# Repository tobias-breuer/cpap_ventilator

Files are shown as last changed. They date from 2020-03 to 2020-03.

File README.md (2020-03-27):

# CPAP Ventilator

CPAP (Continous positive airway pressure)-ventilation is a common form of medical therapy when people suffer from sleep related respiratory problems like sleep apnoa. Worn at night, these masks keep the patients' respiratory tracts open by inducing a continous overpressure. CPAP units are available in large numbers in common households as well as in hospitals.

More information is available [on this page](https://www.uni-marburg.de/de/fb13/halbleiterphotonik/the-breathing-project/the-breathing-project-1/the-cpap-solution).

## Hardware components

### Arduino UNO Schematic Wiring

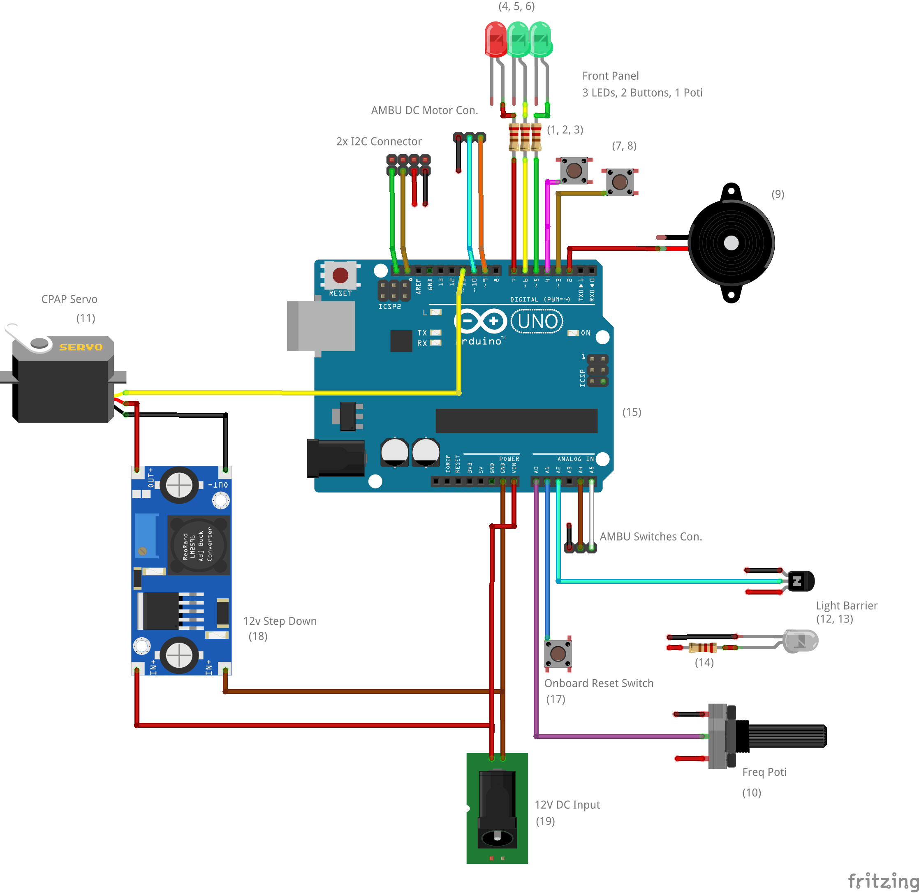
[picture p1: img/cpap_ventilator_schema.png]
Arduino UNO Wiring


### Arduino UNO Pinout

```
  -DPIN_SPEAKER=2
  -DPIN_SWITCH_MODE_A=3
  -DPIN_SWITCH_MODE_B=4
  -DPIN_SWITCH_RESET=A1
  -DPIN_LED_MODE_ONE=5
  -DPIN_LED_MODE_TWO=6
  -DPIN_LED_WARN=7
  -DPIN_SERVO=11
  -DPIN_LIGHT=12
  -DPIN_POTI=A0
  -DPIN_MOTOR_STOP=8
  -DPIN_MOTOR_IN3=9
  -DPIN_MOTOR_IN4=10
```

## Deploying the Code

The project is now maintained as as a [platformio project](https://platformio.org), in order to manage dependencies and compatibility with other platforms.

The project can be build and flashed using:

```
pio run -t upload -e uno_cpap  # for the CPAP board
pio run -t upload -e uno_ambu  # for the Ambu Bag board
```

## Discussion

### Servo latency

The tube is not completely closed until the servo is done. In other words, the
air pressure is practically the same until completed. So we have to subtract the
running time from the time interval until the next closing.

We have measured for 1:1 and 1:2 resulting in an offset of round about 0.18
seconds off. This _magic_ value is removed as `SERVO_CLOSE_LATENCY`.

### EEPROM state

Some state variables, e.g., the cycle counter or the last mode, are stored in
the Arduino's EEPROM. Thus these values can be stored reboot-safe.

However, at the initial boot those values might be not nulled. So the controller
should be reset via the reset button at the first start.

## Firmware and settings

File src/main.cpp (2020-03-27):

#include <Arduino.h>
#include <Wire.h>
#include <LiquidCrystal_I2C.h>

#include "./button.h"
#include "./error.h"
#include "./state.h"

#ifdef MODE_AMBU
#include "./ambu.h"
#elif MODE_CPAP
#include "./cpap.h"
#else
#error neither MODE_AMBU nor MODE_CPAP were specified
#endif

/* Signatures of all following functions */
inline void display_error();
inline void display_status();
inline void read_frequency();
inline void read_mode();
inline void reset();
void loop();
void setup();

/* Reference to the LCD */
LiquidCrystal_I2C lcd(0x27);

/* Variable to measure the breaths per minute */
volatile float breaths_per_minute;

/**
 * Setup the CPAP device. This function is run once while booting up.
 */
void setup() {
  Serial.begin(9600);
  Serial.println("[info] ventilator booting up...");

  // init pins of LEDs as outputs
  pinMode(PIN_LED_MODE_ONE, OUTPUT);
  pinMode(PIN_LED_MODE_TWO, OUTPUT);
  pinMode(PIN_LED_WARN, OUTPUT);
  pinMode(PIN_SPEAKER, OUTPUT);

  // set output signals to low
  digitalWrite(PIN_LED_MODE_ONE, LOW);
  digitalWrite(PIN_LED_MODE_TWO, LOW);
  digitalWrite(PIN_LED_WARN, LOW);
  digitalWrite(PIN_SPEAKER, LOW);

  // init input pins as input with internal pullups
  pinMode(PIN_SWITCH_MODE_A, INPUT_PULLUP);
  pinMode(PIN_SWITCH_MODE_B, INPUT_PULLUP);
  pinMode(PIN_SWITCH_RESET, INPUT_PULLUP);

  // init display
  Wire.begin();
  lcd.begin(16, 2);

  // mode specific setup
#ifdef MODE_AMBU
  ambu_setup();
#elif MODE_CPAP
  cpap_setup();
#endif
}

/**
 * Reset the device's state to a factory mode.
 *
 * This implies a reset of all LEDs and the states stored in the EEPROM.
 * This function should be called after assembly and after the replacement of
 * some hardware.
 */
inline void reset() {
  Serial.println("[warn] entering reset function, cleaning all data...");

#ifdef MODE_AMBU
  ambu_reset();
#elif MODE_CPAP
  cpap_reset();
#endif

  cycle_count_reset();
  mode_reset();

  error = err_none;

  digitalWrite(PIN_LED_MODE_ONE, LOW);
  digitalWrite(PIN_LED_MODE_TWO, LOW);
  digitalWrite(PIN_LED_WARN, LOW);
  digitalWrite(PIN_SPEAKER, LOW);
}

/**
 * Read the mode from the slide switch and notify potential updates.
 */
inline void read_mode() {
  int tmp_mode = mode_read();

  debounce_btn(PIN_SWITCH_MODE_A, 500) { tmp_mode = 0; }
  debounce_btn(PIN_SWITCH_MODE_B, 500) { tmp_mode = 1; }

  if (tmp_mode != mode_read()) {
    mode_write(tmp_mode);
  }
}

/**
 * Read the potentiometer's value and convert it to breaths per minute.
 */
inline void read_frequency() {
  // map the values of the poti to the breaths per minute
  // map() cannot be used, since it only works for int values

  const float poti = analogRead(PIN_POTI);
  breaths_per_minute = (poti - POTI_MIN) * (BPM_MAX - BPM_MIN) / (POTI_MAX - POTI_MIN) + BPM_MIN;
}

/**
 * Display the state on an external LCD display.
 */
inline void display_status() {
  lcd.home();
  lcd.print("Breaths/Min: ");
  lcd.print(breaths_per_minute);
  lcd.setCursor(0, 1);
  lcd.print("In-/Exhale: ");
  lcd.print(mode_get().mult_inhale);
  lcd.print(" ");
  lcd.print(mode_get().mult_exhale);
}

/**
 * Display the error with different blinkings on the warning LED.
 */
inline void display_error() {
  static volatile unsigned long next_blink_switch = 0;

  switch (error) {
    case err_light_barrier:
      // A defect light barrier is critical and results in a permanent light
      digitalWrite(PIN_LED_WARN, HIGH);
      break;

    case err_cycle_count:
      // Exceeding the threshold results in a flashing
      if (next_blink_switch == 0 || (millis() >= next_blink_switch)) {
        next_blink_switch = millis() + WARN_BLINK_MS;
        digitalWrite(PIN_LED_WARN, !digitalRead(PIN_LED_WARN));
      }
      break;

    case err_none:
    default:
      digitalWrite(PIN_LED_WARN, LOW);
  }
}

/**
 * Main loop, which is called endlessly during execution.
 */
void loop() {
  read_mode();

  // show state on the two state LEDs
  digitalWrite(PIN_LED_MODE_ONE, mode_read() == 0);
  digitalWrite(PIN_LED_MODE_TWO, mode_read() == 1);

  read_frequency();

  display_status();

  // warn if cycle_count is greater than MAX_CYCLE_COUNT
  cycle_warn_display();

  // A more urgent specific error might overwrite the previous cycle warning.
#ifdef MODE_AMBU
  ambu_loop();
#elif MODE_CPAP
  cpap_loop();
#endif

  display_error();

  // reset the device if the reset button is pressed
  debounce_btn(PIN_SWITCH_RESET, 1000) {
    reset();
  }
}

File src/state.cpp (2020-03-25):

#include <Arduino.h>
#include <EEPROM.h>

#include "./error.h"
#include "./state.h"

const int eeprom_cycle_count = 0x00;
const int eeprom_mode = eeprom_cycle_count + sizeof(long unsigned int);

/**
 * Variable used for local caching to not query the EEPROM too much.
 * One MUST NOT use this variable. Just use the functions!
 */
long unsigned int cycle_cache = 0;
int mode_cache = -1;

void cycle_count_reset() {
  cycle_cache = 0;
  EEPROM.put(eeprom_cycle_count, cycle_cache);

  Serial.println("[info] writing cycle counter to EEPROM: 0");
}

long unsigned int cycle_count_read() {
  if (cycle_cache == 0) {
    EEPROM.get(eeprom_cycle_count, cycle_cache);
  }

  return cycle_cache;
}

long unsigned int cycle_count_increment() {
  cycle_cache = cycle_count_read() + 1;

  // only store every CYCLE_MOD_SYNC-nth iteration a value
  if ((cycle_cache > 0) && (cycle_cache % CYCLE_MOD_SYNC == 0)) {
    EEPROM.put(eeprom_cycle_count, cycle_cache);

    Serial.print("[info] writing cycle counter to EEPROM: ");
    Serial.println(cycle_cache);
  }

  return cycle_cache - 1;
}

void cycle_warn_display() {
  static bool cycle_warn_raised = false;

  if (cycle_warn_raised) {
    return;
  }

  if (cycle_count_read() >= MAX_CYCLE_COUNT) {
    Serial.println("[warn] reached cycle count threshold");
    error = err_cycle_count;

    cycle_warn_raised = true;
  }
}

void mode_reset() {
  mode_write(0);
}

int mode_read() {
  if (mode_cache == -1) {
    EEPROM.get(eeprom_mode, mode_cache);
  }

  return mode_cache;
}

mode_t mode_get() {
  // update mode_cache, if necessary
  mode_read();

  // return a default iff the value is invalid
  if (mode_cache < 0 || mode_cache >= mode_sizeof) {
    return modes[0];
  }

  return modes[mode_cache];
}

void mode_write(int index) {
  mode_cache = index;
  EEPROM.put(eeprom_mode, mode_cache);

  Serial.print("[info] writing mode to EEPROM: ");
  Serial.println(mode_cache);
}

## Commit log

2020-03-19 Servo_ver2 is just a basic script with rotation around 95 degree and back of the servo ... TwoModeVersion_withAmplitudeControlPot has two modes with blinking LED for OneOne and OneTwo ratio and poten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
2020-03-19 Add files via upload
    added loopcount and LED warning after definable number of loop iterations
2020-03-19 Added LoopReset with blinking LED
2020-03-19 add version with bump sensor (debouncing not correct, yet) ... newest version of amplitudecontrolpot with two modes
2020-03-20 delte basic servo code
2020-03-20 working version for CPAP with 2 modes, LEDs and Speaker warning for loopcount
2020-03-21 Extract pin variables to defines
2020-03-21 Replace interrupt based button with a slide switch
    Also enable basic Serial based logging.
    [main.cpp]
2020-03-21 added fritzing board layout
    [arduino_uno_shield.fzz]
2020-03-21 improved shield layout
    [arduino_uno_shield.fzz]
2020-03-22 Store servo counter in EEPROM
    The number of iterations, previously named loop counter, is now stored
    in the EEPROM to survive reboots.
    [main.cpp]
2020-03-22 Reset device's state with reset button
    [main.cpp]
2020-03-22 Refactor functionality in different files
    Mode related stuff went to src/mode.h and the servo counter went to
    src/servo_count.{h,cpp}.
2020-03-22 added 16x2 i2c display
2020-03-22 added schematic wiring
    [cpap_ventilator_schema.fzz]
2020-03-22 Subtract servo closing latency for state close
    The tube is not completely closed until the servo is done. So we have to
    subtract the running time as a measured constant from the closing time.
2020-03-22 Cache servo counter in flash
2020-03-22 new pin layout
2020-03-22 updated wiring scheme
    [cpap_ventilator_schema.fzz]
2020-03-23 Create an error type to distinguish errors
    [main.cpp]
2020-03-23 Different LED blinking for different warnings
    A broken light barrier leads to a continuous light, while an exceeded
    threshold causes a flashing.
    [main.cpp]
2020-03-24 Generalize servo counter to cycle counter
2020-03-26 Kind-of linear process for Ambu Bag
    Number of revolutions is not identical and must still be adjusted. The mode
    modifier is also still missing.
    [ambu.cpp]
2020-03-26 Configure mode via push buttons
    Cherry picked from da8281299e3ccc2ba075c2644ff33d4adb774344
2020-03-26 Adjust servo time settings for CPAP
    Cherry picked from
    - 8214bbec71ed45084be9081582badfc03dbf6a96
    - 4dad903d3b4baabfc4749efe9b53d5727eb48ea7
2020-03-26 Debouncing macro for buttons/switches
2020-03-26 Delay button execution within debounce_btn
2020-03-26 Adjust CPAP Servo pulse width for MC-410
2020-03-27 Reset mode in EEPROM as part of the reset
    [main.cpp]
2020-03-27 updated wiring schema
    [arduino_uno_shield.fzz, cpap_ventilator_schema.fzz]
2020-03-27 fixed wrong wording
    [cpap_ventilator_schema.fzz]
